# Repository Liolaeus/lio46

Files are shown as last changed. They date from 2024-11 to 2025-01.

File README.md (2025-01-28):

# Lio46 V2

Lio46 is a wireless, 46 key keyboard with my personal best layout in mind.  

# Notable features
- Wireless split keyboad
- 46 keys (23 per side), 4 thumb keys, one extra key on ring column
- Hot-swappable low profile kailh choc v1 switches
- Column staggered with aggressive pinky stagger
- Powered by [ZMK](https://zmk.dev/)
- Generated with [ergogen](https://github.com/ergogen/ergogen) 

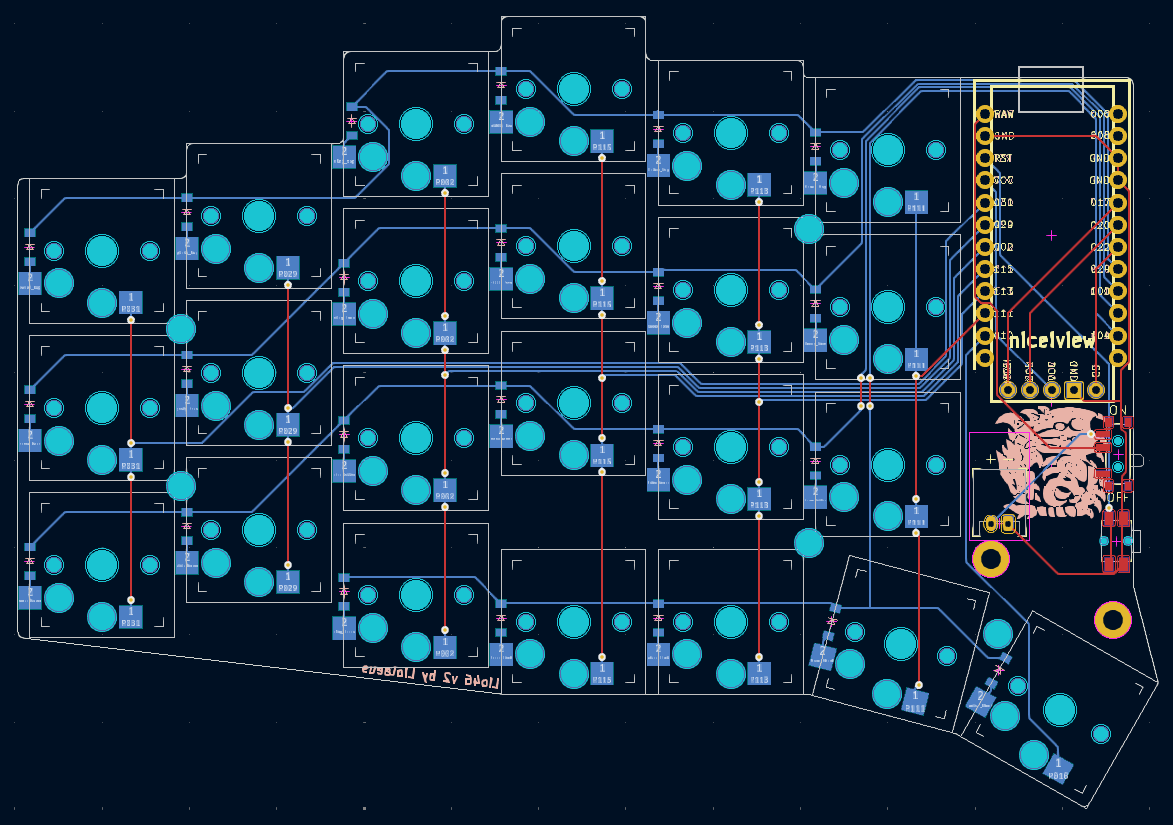
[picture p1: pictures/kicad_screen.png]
kicad screenshot

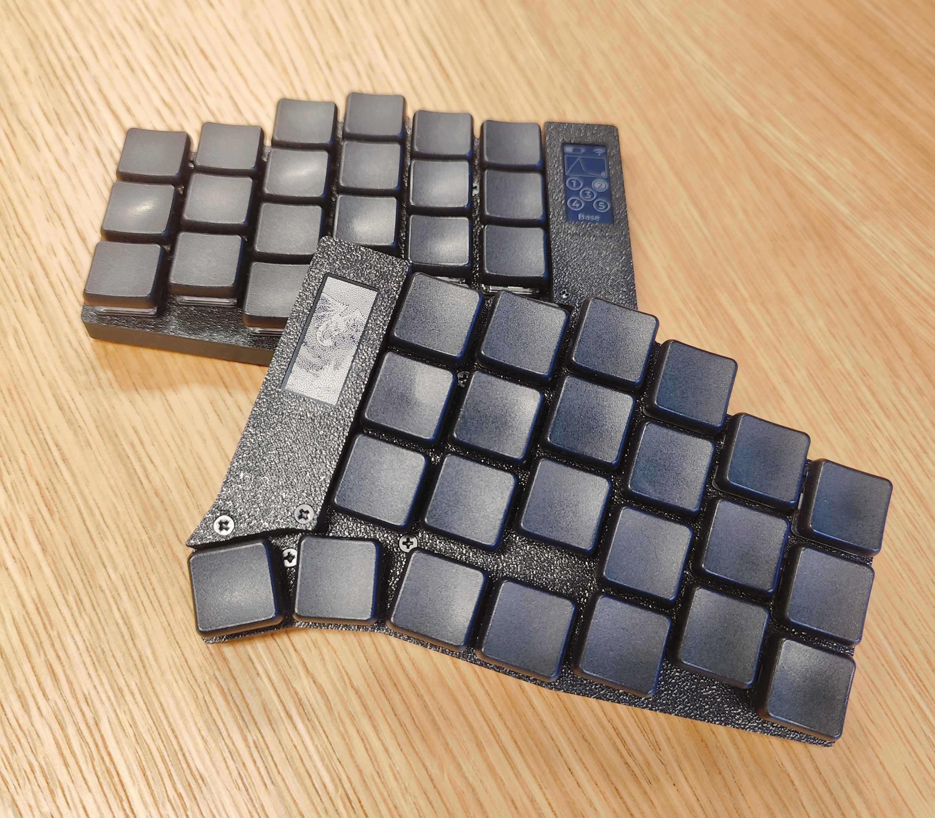
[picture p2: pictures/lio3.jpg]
Lio 46 top

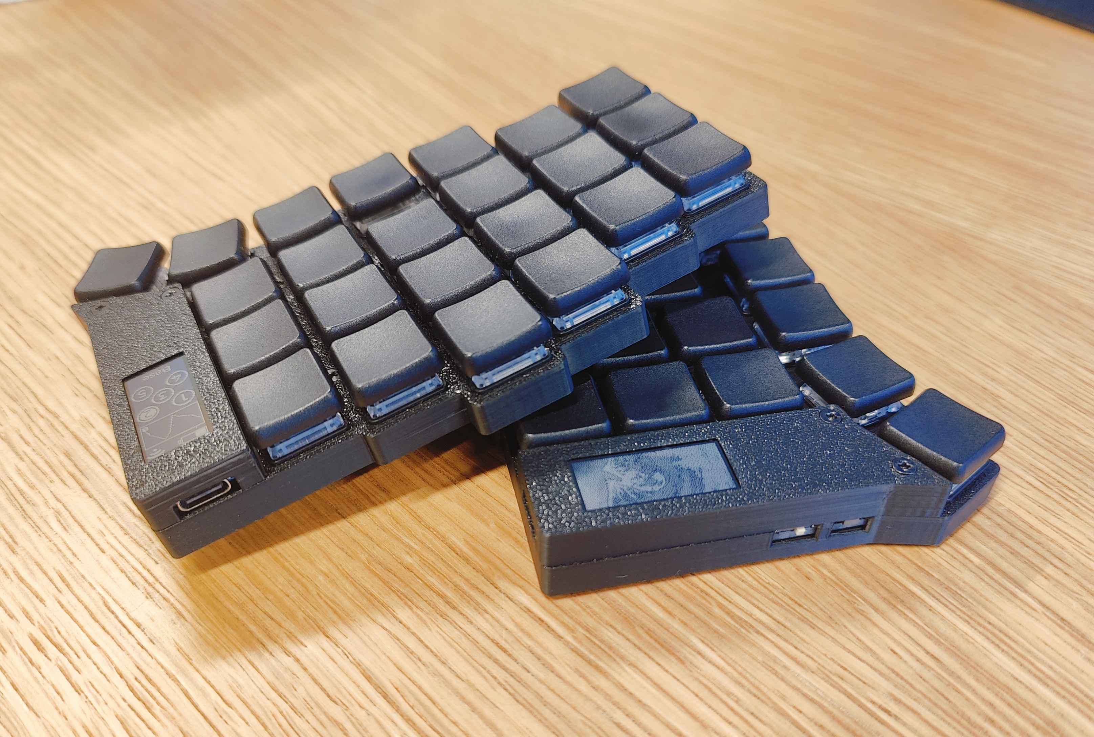
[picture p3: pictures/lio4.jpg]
Lio 46 side


more pictures [here](https://github.com/Liolaeus/lio46/tree/master/pictures) !

# V2 Changelog
- Removed underglow and backlight leds for better battery life
- Moved the thumb keys inwards
- Manual routing
- Fixed logo placement on the pcb
- Moved srew/standoff holes
- Trimmed edges of pcb
- Moved battery connector
- Added a case
- Moved key and display pins
- Supports E-ink nice view displays

# Firmware
You can find and modify the ZMK firmware for this keybaord [here](https://github.com/Liolaeus/lio46-zmk-config).

# Requirements
If you want to modify this keyboard here is the list of software dependencies to run all the scripts in this repository:

- GNU make
- ergogen
- kicad 8
- docker
- python

# Parts
If you want to build this keyboard, you can find all the parts [here](https://github.com/Liolaeus/lio46/blob/master/parts.md)

# References
A list of projects and tools that were used and/or taken inspiration from for the creation of this project, many thanks to all of them.

- [ZMK Firmware](https://zmk.dev/)
- [Sofle ZMK config](https://github.com/zmkfirmware/zmk/tree/0820991901a95ab7a0eb1f1cc608a631d514e26c/app/boards/shields/sofle)
- [Ergogen](https://github.com/ergogen/ergogen)
- [Freerouting](https://github.com/freerouting/freerouting)
- [Flatfootfox blog](https://flatfootfox.com/ergogen-part1-units-points/)
- [SpUnLy58 keyboard](https://github.com/Giraffasax/SpUnLy58/tree/main)
- [Corney-island keyboard](https://github.com/ceoloide/corney-island)
- [NostrumX keyboard](https://github.com/bennytrouser/NostrumX/tree/main)
- [Caldera keyboard](https://github.com/christianselig/caldera-keyboard/tree/main)
- [Avalanche keyboard](https://github.com/vlkv/avalanche/tree/master)

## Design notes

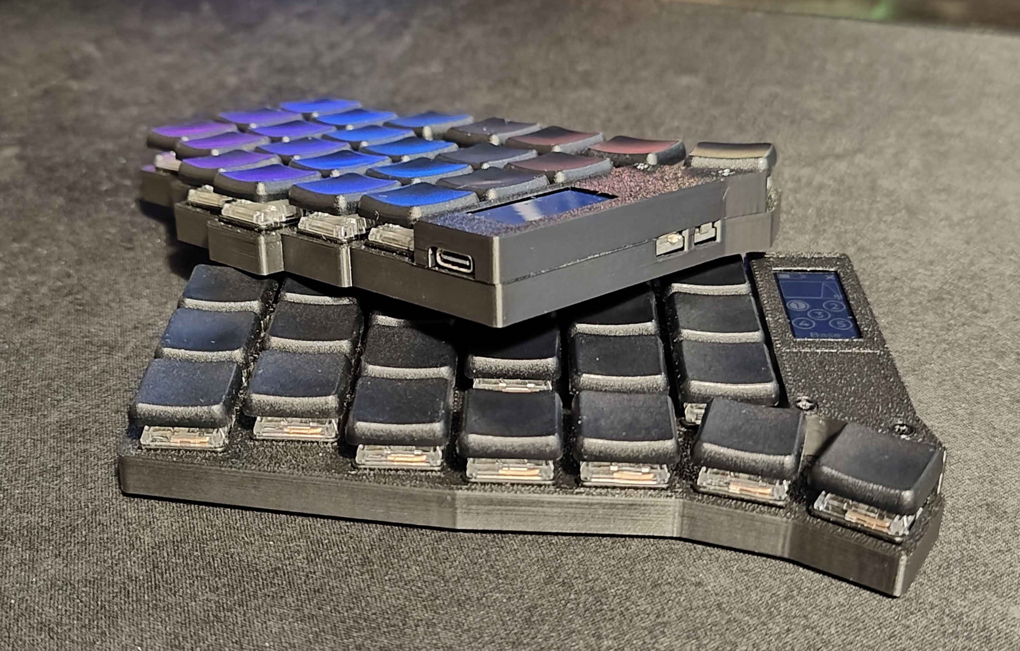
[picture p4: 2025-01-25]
pictures/lio1.jpg

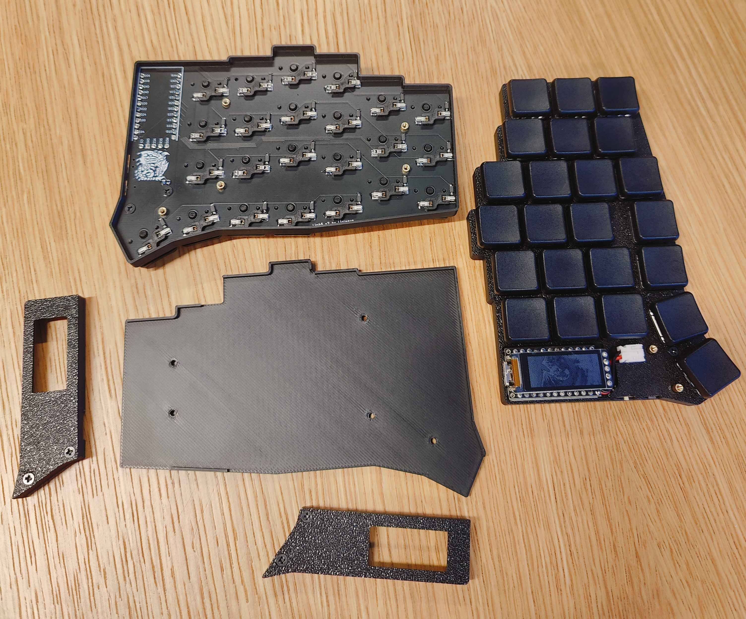
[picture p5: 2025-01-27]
pictures/lio5.jpg

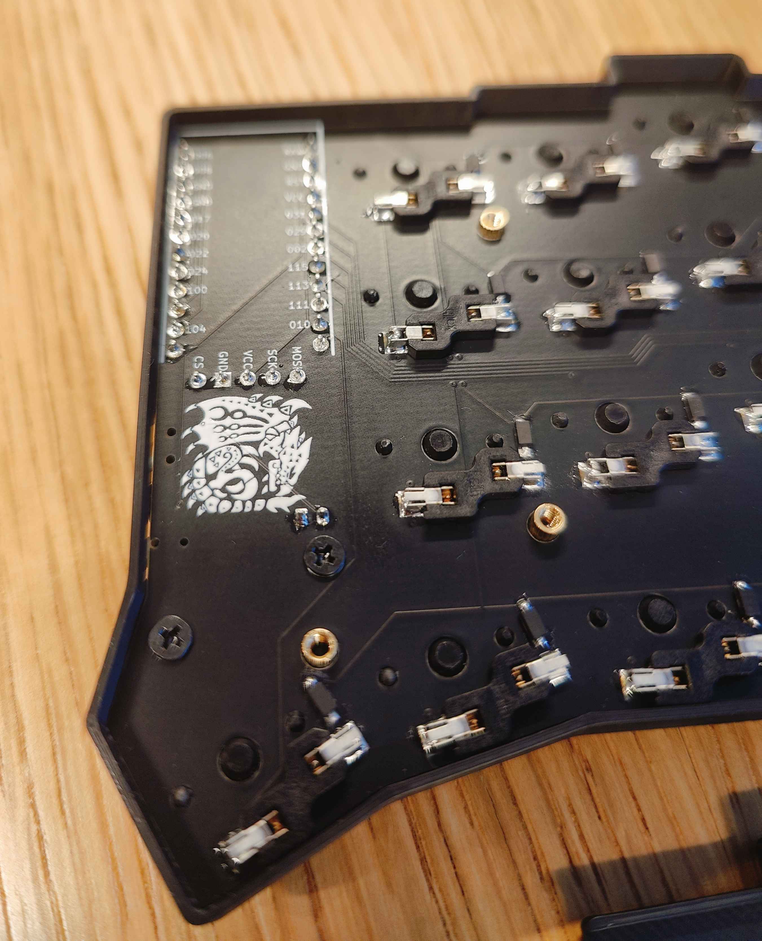
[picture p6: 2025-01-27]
pictures/lio6.jpg

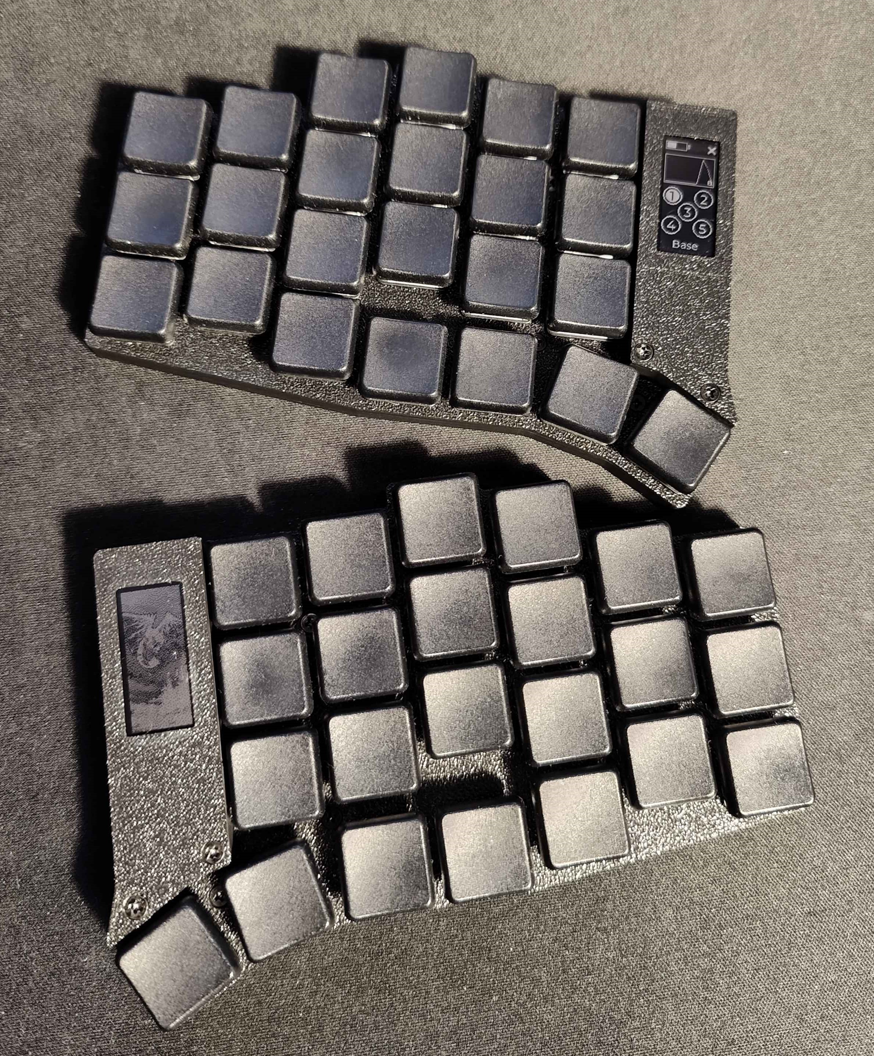
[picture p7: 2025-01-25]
pictures/lio2.jpg

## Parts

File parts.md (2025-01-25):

# List of parts to build a Lio46

| Part | Quantity | Source |
| --- | --- | --- |
| PCB | 2 | Ordered from JLCPCB |
| Kailh choc v1 switches | 46 | https://www.aliexpress.com/item/1005005446722280.html |
| Kailh choc keycaps | 46 | https://www.aliexpress.com/item/1005004558099208.html |
| Kailh hotswap sockets (low profile) | 46 | https://www.aliexpress.com/item/1005003873653184.html |
| Controllers (Nice!Nano or SuperMini NRF52840) | 2 | https://nicekeyboards.com/nice-nano#find-a-store or https://www.aliexpress.com/item/1005007040333351.html |
| Controllers (Nice!View or ) | 2 | https://nicekeyboards.com/nice-view#find-a-store or https://www.aliexpress.com/item/1005008112752514.html |
| Controller hotswap sockets (12 pins) | 4 | https://www.aliexpress.com/item/1005007476809536.html |
| Dipslay hotswap sockets (5 pins) | 2 | https://www.aliexpress.com/item/1005007476809536.html |
| Controller / Display pins 0.6x5 mm | 58 | https://www.aliexpress.com/item/1005006678285929.html |
| Diodes | 46 | https://www.aliexpress.com/item/4000685043735.html |
| Reset button | 2 | https://www.aliexpress.com/item/32802358763.html |
| ON/OFF switch | 2 | https://www.aliexpress.com/item/32963237441.html |
| Batteries (3.7V 110mAh 301230, 2mm JST connector) | 2 | https://www.aliexpress.com/item/1005005348368664.html |
| JST 2mm battery connector (female side mount) | 2 | https://www.aliexpress.com/item/1005004955655144.html |
| M2 screws (3mm) | 24 | https://www.aliexpress.com/item/1005005590438825.html |
| M2 screws (6mm) | 4 | https://www.aliexpress.com/item/1005005590438825.html |
| M2 standoffs (female-female, 5mm) | 14 | https://www.aliexpress.com/item/1005007524730354.html |
| Rubber feet (6x2mm) | 12 | https://www.aliexpress.com/item/1005004366514224.html |

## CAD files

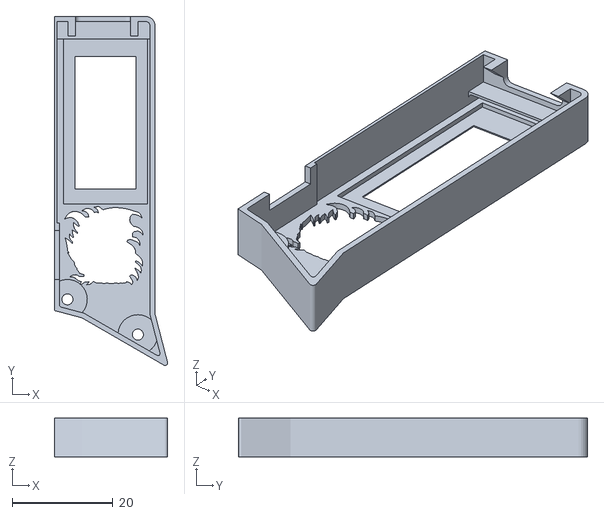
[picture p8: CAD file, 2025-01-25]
case/screen_cover_right.stl
22.5 x 69.3 x 7.70

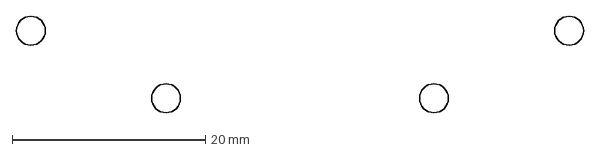
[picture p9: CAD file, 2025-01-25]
ergogen/output/outlines/mounting_holes.dxf
58.8 x 10.0 mm

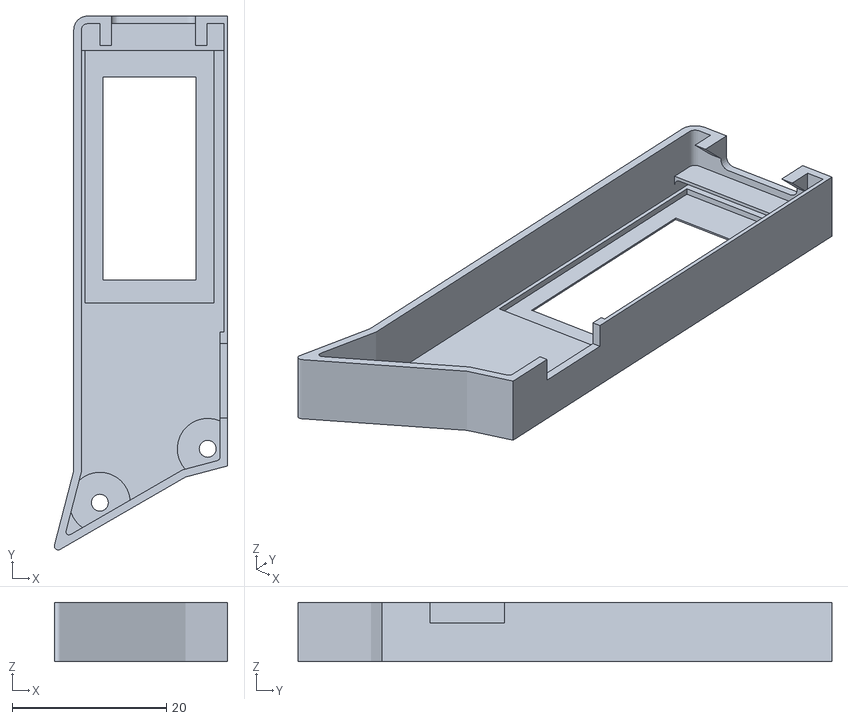
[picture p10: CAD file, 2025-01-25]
case/screen_cover_left_no_logo.stl
22.5 x 69.3 x 7.70

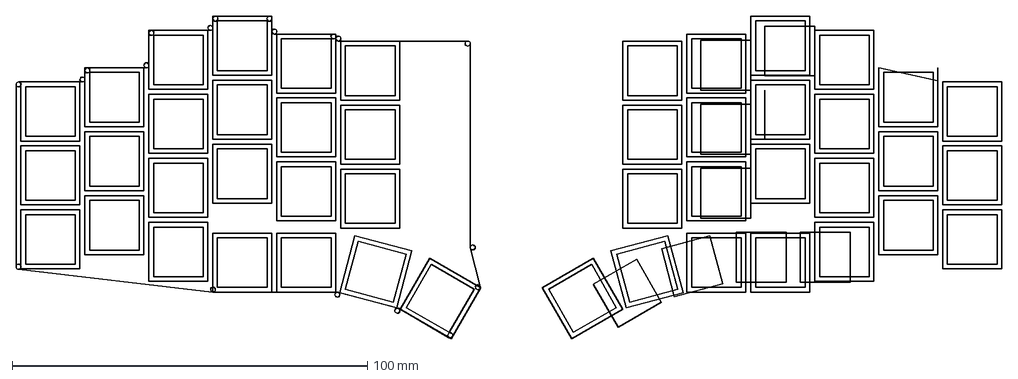
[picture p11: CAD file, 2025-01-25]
ergogen/output/outlines/combo.dxf
277.3 x 90.7 mm

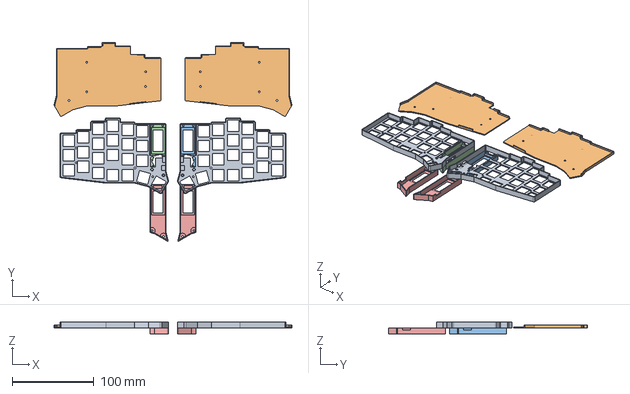
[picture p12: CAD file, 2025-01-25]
case/case_lio.step
291.0 x 243.1 x 15.0 mm

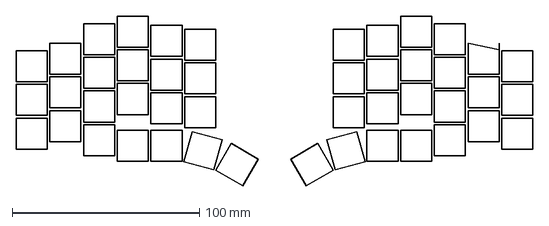
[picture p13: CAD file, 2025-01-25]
ergogen/output/outlines/keycaps.dxf
276.0 x 90.7 mm

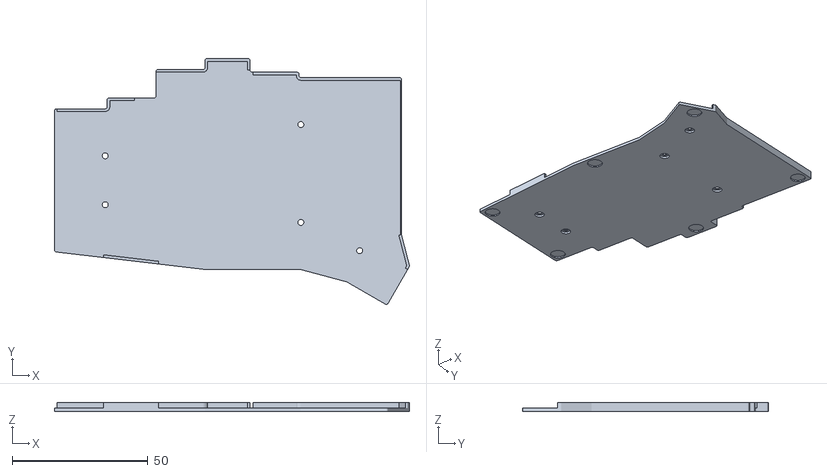
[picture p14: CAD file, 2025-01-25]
case/bottom_plate_left.stl
130.6 x 90.5 x 3.20

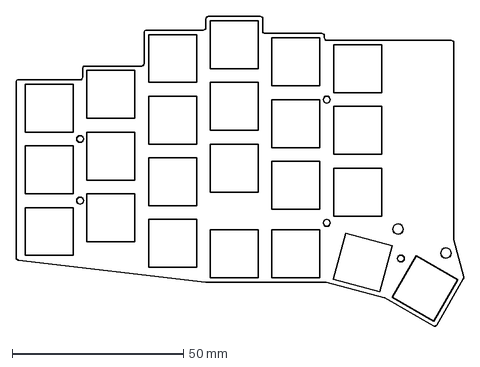
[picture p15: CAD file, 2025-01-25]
ergogen/output/outlines/case.dxf
130.6 x 90.6 mm

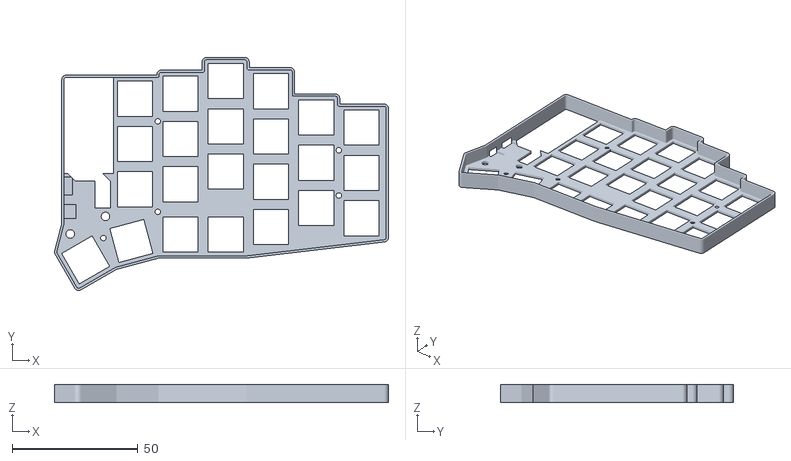
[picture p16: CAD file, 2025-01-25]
case/top_case_left.stl
132.8 x 92.7 x 7.30

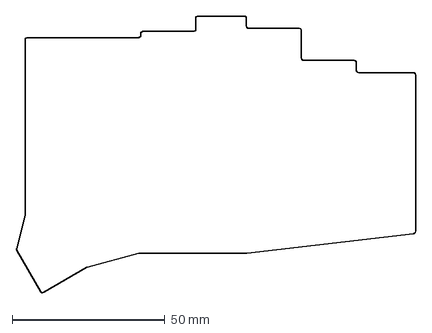
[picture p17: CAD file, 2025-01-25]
ergogen/output/outlines/pcb_right.dxf
130.6 x 90.6 mm

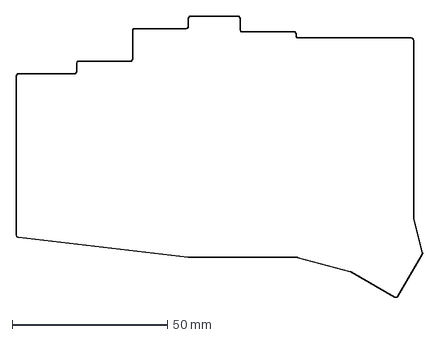
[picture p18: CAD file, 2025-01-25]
ergogen/output/outlines/pcb_left.dxf
130.6 x 90.6 mm

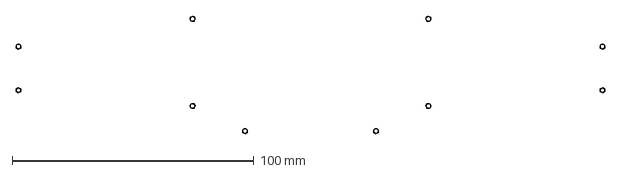
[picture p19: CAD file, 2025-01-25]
ergogen/output/outlines/standoff_holes.dxf
243.4 x 48.4 mm

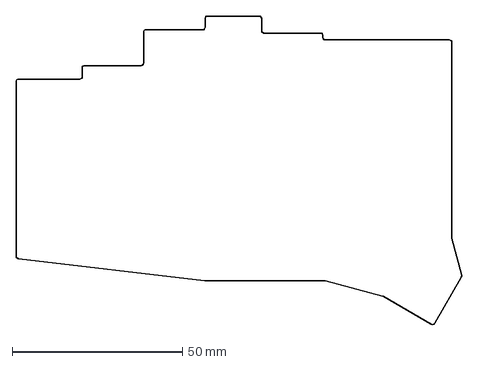
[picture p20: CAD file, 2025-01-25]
ergogen/output/outlines/switch_plate.dxf
130.6 x 90.6 mm

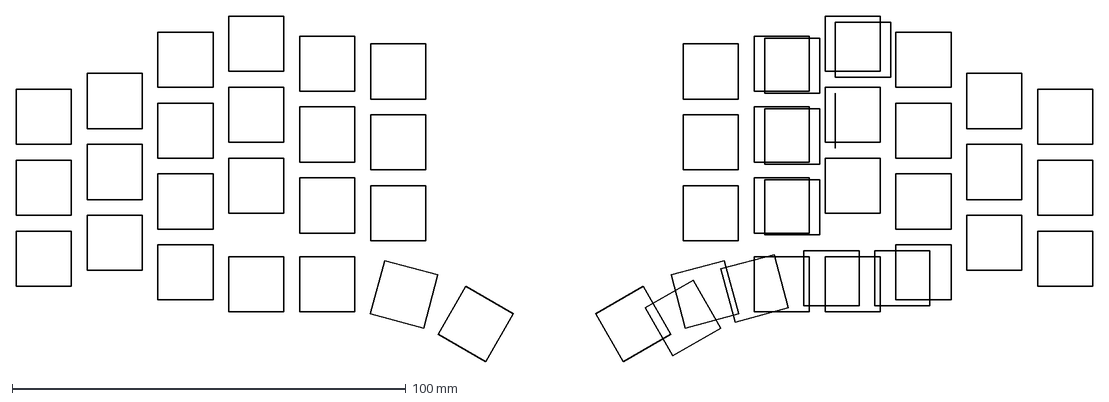
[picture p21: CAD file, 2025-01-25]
ergogen/output/outlines/cutouts.dxf
273.4 x 87.7 mm

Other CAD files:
case/top_case_right.stl
case/screen_cover_right_no_logo.stl
case/bottom_plate_right.stl
case/screen_cover_left.stl
case/case_lio.f3d
ergogen/output/outlines/controller.dxf
ergogen/output/outlines/plate_left.dxf
ergogen/output/outlines/plate_right.dxf

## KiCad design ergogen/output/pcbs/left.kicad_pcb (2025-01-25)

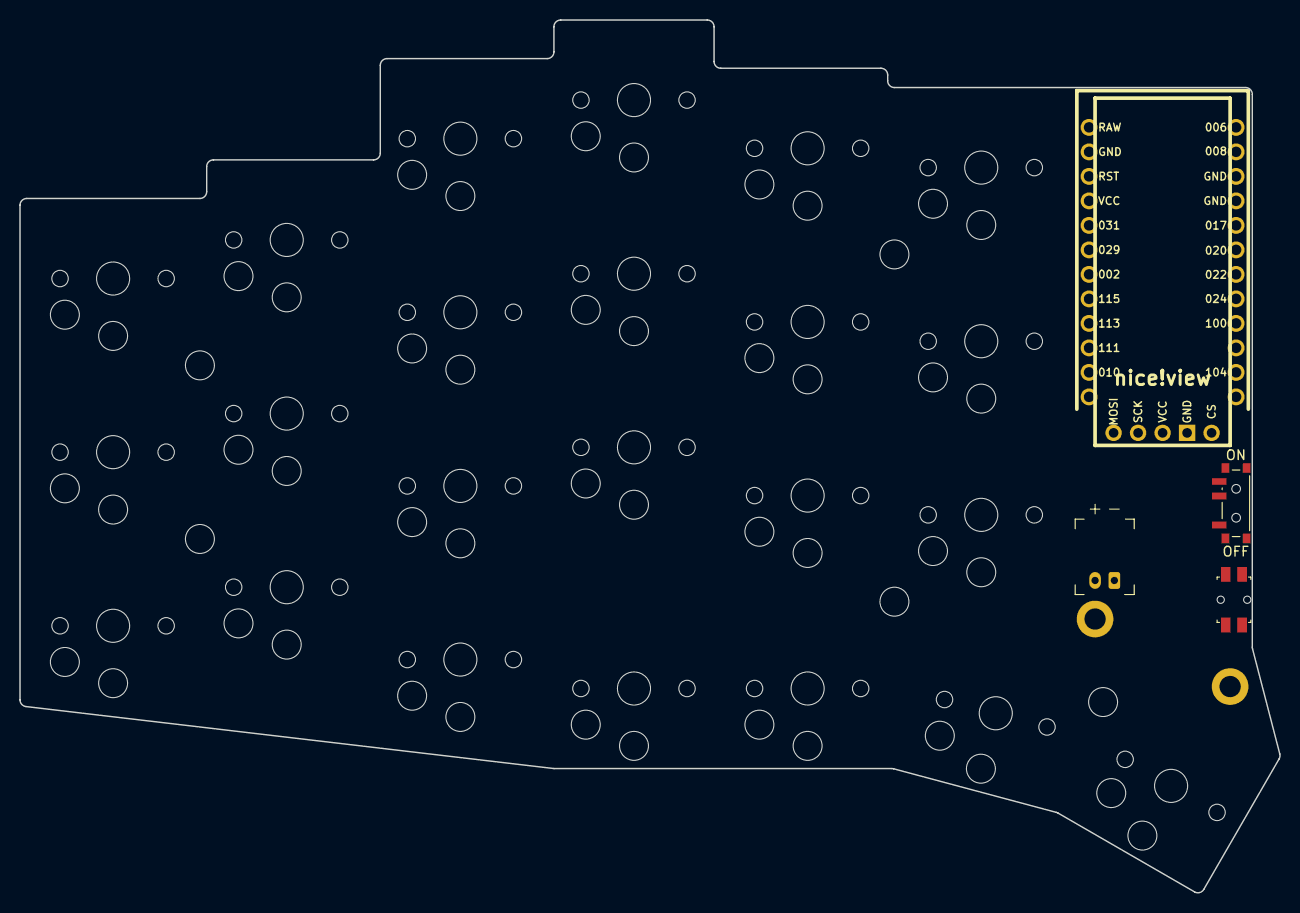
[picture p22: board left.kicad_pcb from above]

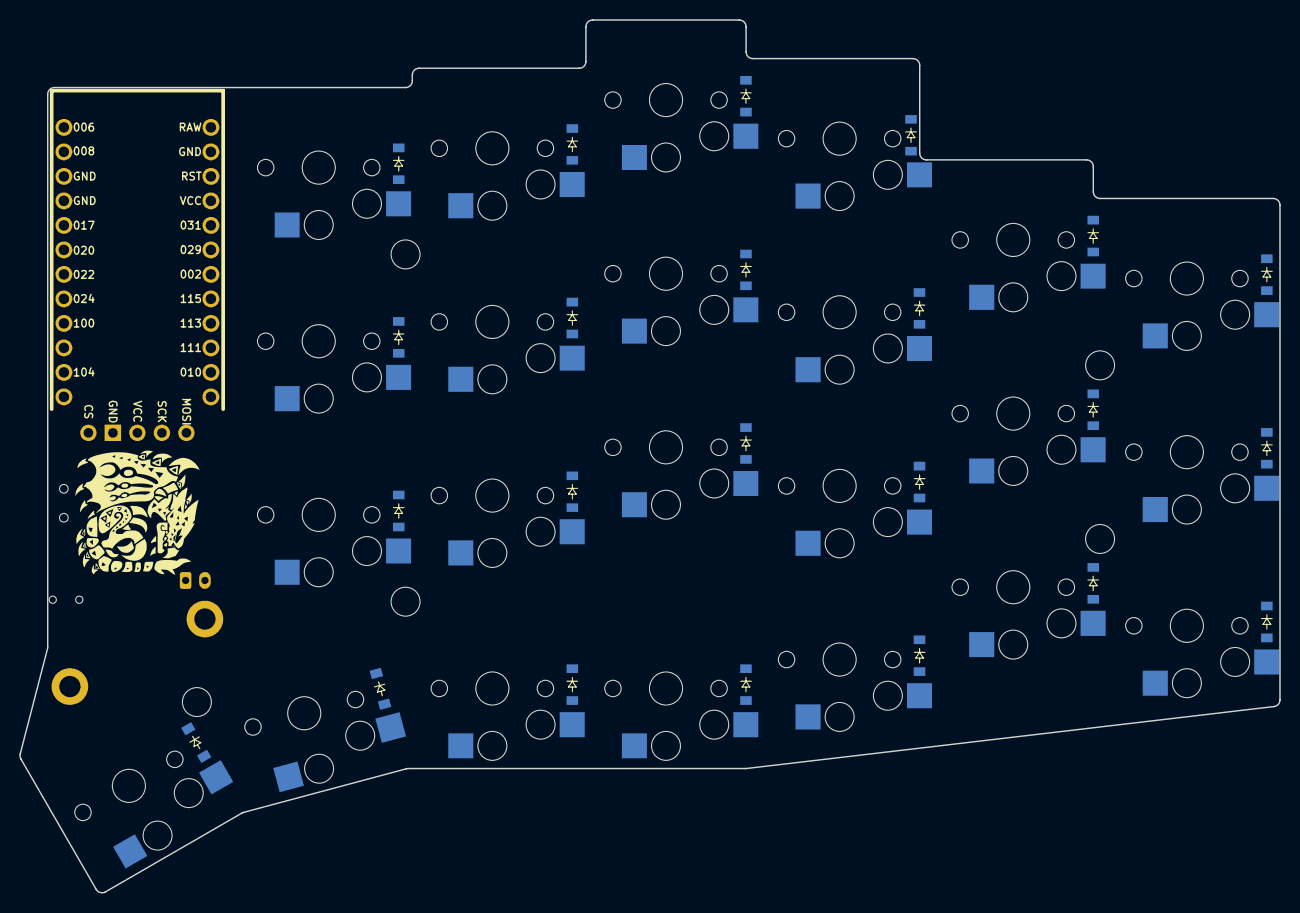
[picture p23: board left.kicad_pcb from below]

Board: 2 copper layers, 130.6 x 90.5 mm, 59 parts (24 on the bottom side), 42 nets, no tracks yet.

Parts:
D1, D2, D3, D4, D5, D6, D7, D8, D9, D10, D11, D12, D13, D14, D15, D16, D17, D18, D19, D20, D21, D22, D23: diode_tht_sod123
G: Lio; lio
H1, H2: mounting_hole_plated
JST1: battery_connector_jst_ph_2
MCU1: nice_nano
MH1, MH2, MH3, MH4, MH5: mounting_hole_npth
PWR1: power_switch_smd_side
RST1: reset_switch_smd_side
S1, S2, S3, S4, S5, S6, S7, S8, S9, S10, S11, S12, S13, S14, S15, S16, S17, S18, S19, S20, S21, S22, S23: PG1350
niceView1: niceView; niceView_headers

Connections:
BAT_P: JST1.2, PWR1.3
GND: JST1.1, MCU1.3, MCU1.4, MCU1.23, RST1.1, RST1.3, niceView1.2
P002: MCU1.18, S7.1, S8.1, S9.1, S10.1
P010: MCU1.14, S23.1
P011: D1.1, D4.1, D8.1, D10.1, D13.1, D16.1, MCU1.10
P017: MCU1.5, niceView1.5
P020: MCU1.6, niceView1.4
P022: MCU1.7, niceView1.1
P024: D3.1, D6.1, D12.1, D15.1, D18.1, D23.1, MCU1.8
P029: MCU1.19, S4.1, S5.1, S6.1
P031: MCU1.20, S1.1, S2.1, S3.1
P100: D2.1, D5.1, D9.1, D11.1, D14.1, D17.1, MCU1.9
P104: D7.1, D19.1, D20.1, D21.1, D22.1, MCU1.11
P111: MCU1.15, S17.1, S18.1, S19.1, S22.1
P113: MCU1.16, S14.1, S15.1, S16.1, S21.1
P115: MCU1.17, S11.1, S12.1, S13.1, S20.1
RAW: MCU1.24, PWR1.2
RST: MCU1.22, RST1.2, RST1.4
VCC: MCU1.21, niceView1.3
close_thumb: D20.2, S21.2
home_thumb: D21.2, S22.2
index_bottom: D13.2, S14.2
index_home: D14.2, S15.2
index_top: D15.2, S16.2
inner_bottom: D16.2, S17.2
inner_home: D17.2, S18.2
inner_thumb: D19.2, S20.2
inner_top: D18.2, S19.2
middle_bottom: D10.2, S11.2
middle_home: D11.2, S12.2
middle_top: D12.2, S13.2
outer_bottom: D1.2, S1.2
outer_home: D2.2, S2.2
outer_thumb: D22.2, S23.2
outer_top: D3.2, S3.2
pinky_bottom: D4.2, S4.2
pinky_home: D5.2, S5.2
pinky_top: D6.2, S6.2
ring_bonus: D7.2, S7.2
ring_bottom: D8.2, S8.2
ring_home: D9.2, S9.2
ring_top: D23.2, S10.2

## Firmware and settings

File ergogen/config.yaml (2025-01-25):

units:
  kcs: 16.6 # Key Cap Size (of a square choc v1 keycap)
  cos: 14 # Cut Out Size, switch insert footprint in fr4
  border_offset: 0.5kcs
  cx: 18
  cy: 17
  vertical_underglow_shift: -10 # How much to shift underglow leds tied to keys

points:
  key:
    padding: kcs + 1.4
    spread: kcs + 1.4
  zones:
    matrix:
      anchor:
        shift: [170, -190] # position on kicad sheet
      key:
        tags:
          - switch
      rows:
        bonus:
          row_net: P104
        bottom:
          row_net: P011
        home:
          row_net: P100
        top:
          row_net: P024
      columns:
        outer:
          rows:
            bonus.skip: true
          key:
            column_net: P031
        pinky:
          rows:
            bonus.skip: true
          key:
            stagger: 4
            column_net: P029
        ring:
          key:
            stagger: 10.5
            column_net: P002
        middle:
          rows:
            bonus.skip: true
          key:
            stagger: 4
            column_net: P115
        index:
          rows:
            bonus.skip: true
          key:
            stagger: -5
            column_net: P113
        inner:
          rows:
            bonus.skip: true
          key:
            stagger: -2
            column_net: P111
    thumbfan:
      rows:
        thumb:
          row_net: P104
      anchor:
        ref: matrix_inner_bottom
        shift: [-36, -18]
      columns:
        inner:
          key:
            column_net: P115
        close:
          key:
            column_net: P113
        home:
          key:
            spread: 18
            splay: -15
            origin: [-9, -7]
            column_net: P111
        outer:
          key:
            spread: 18
            splay: -15
            origin: [-9, -7]
            column_net: P010

    controller:
      anchor:
        - ref: matrix_inner_top
          shift: [kcs + 2.2, -9.8]
    nice_view:
      anchor:
        - ref: controller
          shift: [0, -19]
    pwr_sw:
      anchor:
        - ref: controller
          shift: [7.6, -25]
    rst_button:
      anchor:
        - ref: controller
          shift: [7.4, -35]
    bat_con:
      anchor:
        - ref: controller
          shift: [-6, -33]
    logo:
      anchor:
        - ref: controller
          shift: [0, -26]

    standoff_hole_1:
      anchor:
        - ref: matrix_inner_top
          shift: [-9, -9]
    standoff_hole_2:
      anchor:
        - ref: matrix_outer_home
          shift: [9, 9]
    standoff_hole_3:
      anchor:
        - ref: matrix_outer_bottom
          shift: [9, 9]
    standoff_hole_4:
      anchor:
        - ref: matrix_inner_bottom
          shift: [-9, -9]
    standoff_hole_5:
      anchor:
        - ref: thumbfan_outer_thumb
          shift: [-10.45, 4]


    mounting_hole_6:
      anchor:
        - ref: nice_view
          shift: [-7, -18]
    mounting_hole_7:
      anchor:
        - ref: nice_view
          shift: [7, -25]

  mirror:
    ref: thumbfan_outer_thumb
    distance: 40
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

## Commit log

2024-10-15 add: ergogen config and footprints
    [combo.dxf, controller.dxf, cutouts.dxf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]
2024-10-18 fix: button positions
    [left.kicad_pcb]
2024-10-20 add: component placement, niceview, mirror pcb
    [combo.dxf, controller.dxf, cutouts.dxf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]
2024-10-22 fix: ergogen lio logo
    [left.kicad_pcb, right.kicad_pcb]
2024-11-03 add: routing paras, position adjustments
    [left.kicad_pcb, right.kicad_pcb]
2024-11-12 update: nice_view pins
    [left.kicad_pcb, right.kicad_pcb]
2024-11-15 fix: diode / hole / led placement
    [left.kicad_pcb, pcb.dxf, right.kicad_pcb]
2024-11-16 add: generated files
    [combo.dxf, controller.dxf, cutouts.dxf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]
2024-11-16 add: gerber files
    [left.dsn, left_routed.kicad_pcb, right.dsn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]
2024-12-11 add: rebuild ergogen on footprint modification
2024-12-11 wip: v2
    [combo.dxf, left.kicad_pcb, pcb_left.dxf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]
2024-12-14 wip: unrouted v2
    [combo.dxf, controller.dxf, cutouts.dxf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]
2024-12-15 wip: right routed
    [lef_routed.kicad_pcb, left.kicad_pcb, right.kicad_pcb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]
2024-12-16 wip: change nice view pins / reroute
    [left.kicad_pcb, left_routed.kicad_pcb, left_routed_2.kicad_pcb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]
2024-12-18 add: v2 gerbers
    [left.kicad_pcb, left_routed.kicad_pcb, left_routed_2.kicad_pcb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]
2025-01-01 add: case / switchplate
    [combo.dxf, keycaps.dxf, plate_left.dxf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]
2025-01-05 add: case files
    [case.dxf, case_lio.f3d, case_lio.stl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]
2025-01-25 update: case
    [case_lio.f3d, case_lio.step, screen_cover_left_no_logo.stl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]
